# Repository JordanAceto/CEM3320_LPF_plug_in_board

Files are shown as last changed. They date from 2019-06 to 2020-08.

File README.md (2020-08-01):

# NOTE: development of all VCF plug-in boards has been moved here https://github.com/JordanAceto/VCF_plug_in_boards
### This repo will no longer be updated. Follow the above link for the most current files.

# CEM3320 Plug-In Board

Small CEM3320 based low pass filter PCB, designed to plug into a larger motherboard.

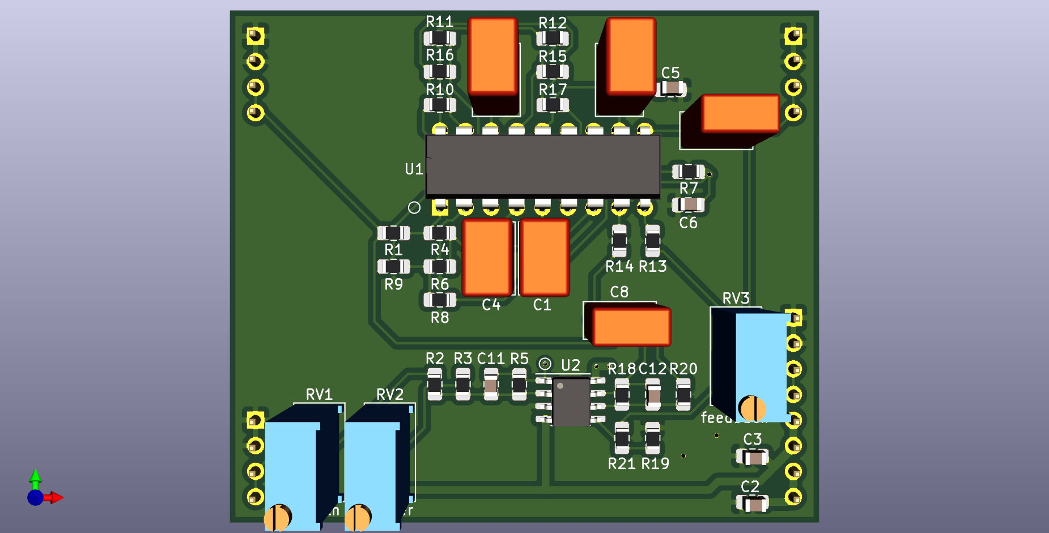
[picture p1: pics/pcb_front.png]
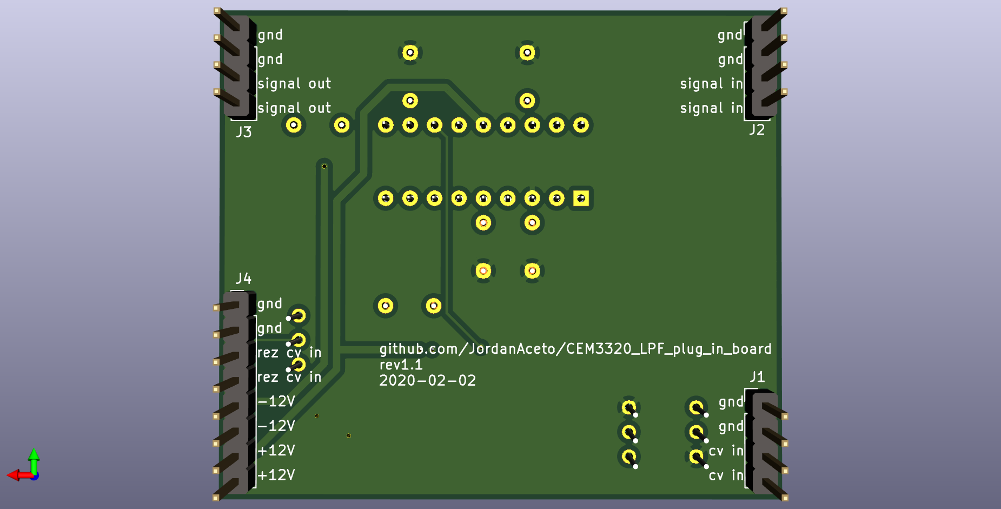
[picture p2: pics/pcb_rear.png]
 

## Details

CEM3320 based LPF with Q compensation. This PCB includes the audio path and CV inputs for frequency and feedback, but does not include any modulation sources.

The intended use for this board is to plug in to a larger motherboard which contains slots for two of these plug-in boards, as well as modulation sources, panel controls, and input/output routing. This motherboard could accept different filter boards sharing this footprint and header layout, for realizing stereo effects of various flavors.

The Q compensation circuit keeps the passband gain from dropping too much when feedback is increased as typically happens with this type of filter. This is a matter of taste. The amount of compensation is set by R20. R20 can be increased to reduce the amount of compensation, resulting in lower passband gain at high feedback settings if a more traditional response is desired.

## Inputs

-Audio in: dry audio input to be filtered.

-Frequency CV in: 0 volts to +2.048 volts, higher voltage = higher sweep.

-Feedback CV in: 0 volts to +2.048 volts, higher voltage = more feedback.

## Outputs

-Audio out: filtered audio output.

## Power Supply Requirements

A bipolar 12 volt power supply is required. This will typically come from the motherboard.

## Calibration

-RV1 (depth trim): trims the depth of incoming frequency CV signals. Turn CW for greater depth and CCW for less depth. Adjust to taste.

-RV2 (center trim): trims the center frequency of the filter. Turn CW for higher center frequency and CCW for lower center frequency. Adjust to taste.

-RV3 (feedback trim): trims the maximum amount of feedback. Turn CW for more maximum feedback and CCW for less maximum feedback. Exercise caution when adjusting this, as extreme settings can result in loud oscillations which could damage your ears or speakers if you are monitoring the sound with a loud amplifier. If you set this trimmer to be right on the edge of oscillation when about +2 volts is applied to the feedback CV input then make sure to sweep the frequency through its entire range, as a setting that doesn't squeal at certain frequency settings may squeal at other settings.

## Parts Ordering
The BOM has a link to a Mouser project with the majority of the parts needed to build the board, with the exception of the CEM3320. There is a link to the synthcube parts page, where the AS3320 is available. This is a functionally equivalent part that is currently in production.

Gerbers can be generated from the kicad_docs.

## License
CC by 4.0

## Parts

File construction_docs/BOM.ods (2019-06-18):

Reference | Quantity | Value | Footprint | Unit Price | Total Price | Product Page
Mouser Parts
C1 C4 C7 C9 | 4 | 220pF | Capacitor_THT:C_Rect_L7.0mm_W4.5mm_P5.00mm | $0.43 | $1.72 | https://www.mouser.com/ProductDetail/WIMA/FKP2D002201D00HSSD?qs=sGAEpiMZZMv1cc3ydrPrFwgzP98AO9idFG3Dn44LbVs%3D
C11 C12 | 2 | 100pF | 0805 | $0.10 | $0.20 | https://www.mouser.com/ProductDetail/KEMET/C0805C101K1HACTU
C5 C6 C2 C3 | 4 | 100nF | 0805 | $0.10 | $0.40 | https://www.mouser.com/ProductDetail/KEMET/C0805C104M5RACTU
C8 C10 | 2 | 470nF | Capacitor_THT:C_Rect_L7.0mm_W3.5mm_P5.00mm | $0.29 | $0.58 | https://www.mouser.com/ProductDetail/WIMA/MKS2C034701C00MSSD
J1 J2 J3 J4 | 1 | breakaway headers | 2.54mm PinHeader | $2.78 | $2.78 | https://www.mouser.com/ProductDetail/TE-Connectivity/4-103185-0
R1 R6 R10 R15 | 4 | 91k | 0805 | $0.12 | $0.48 | https://www.mouser.com/ProductDetail/Bourns/CR0805-FX-9102ELF
R13 | 1 | 18k | 0805 | $0.10 | $0.10 | https://www.mouser.com/ProductDetail/Bourns/CR0805-FX-1802ELF
R14 | 1 | 51k | 0805 | $0.10 | $0.10 | https://www.mouser.com/ProductDetail/Bourns/CR0805-FX-5102ELF
R20 | 1 | 150k | 0805 | $0.10 | $0.10 | https://www.mouser.com/ProductDetail/Bourns/CR0805-FX-1503ELF
R3 | 1 | 330k | 0805 | $0.10 | $0.10 | https://www.mouser.com/ProductDetail/Bourns/CR0805-FX-3303ELF
R4 R9 R12 R17 R2 R18 R21 R19 | 8 | 100k | 0805 | $0.10 | $0.80 | https://www.mouser.com/ProductDetail/Bourns/CR0805-FX-1003ELF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
R5 | 1 | 10k | 0805 | $0.10 | $0.10 | https://www.mouser.com/ProductDetail/Bourns/CR0805-FX-1002ELF
R7 | 1 | 1k2 | 0805 | $0.10 | $0.10 | https://www.mouser.com/ProductDetail/Bourns/CR0805-FX-1201ELF
R8 R11 R16 | 3 | 180k | 0805 | $0.10 | $0.30 | https://www.mouser.com/ProductDetail/Bourns/CR0805-FX-1803ELF
RV1 | 1 | 10k | Bourns_3269W_Vertical | $4.83 | $4.83 | https://www.mouser.com/ProductDetail/Bourns/3269W-1-103LF?qs=sGAEpiMZZMvygUB3GLcD7lKKmqkeksZmGot4dXELruo%3D
RV2 RV3 | 2 | 100k | Bourns_3269W_Vertical | $4.83 | $9.66 | https://www.mouser.com/ProductDetail/Bourns/3269W-1-104LF?qs=sGAEpiMZZMvygUB3GLcD7iPUMwpiXMBsQtXtzdbyTwg%3D
U2 | 1 | TL072 | SOIC-8 | $0.59 | $0.59 | https://www.mouser.com/ProductDetail/Texas-Instruments/TL072CDR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
 |  |  | Mouser total: |  | $22.94
 |  |  | Link To Mouser Project: |  |  | https://www.mouser.com/ProjectManager/ProjectDetail.aspx?AccessID=8d3da38cff
Non-Mouser Parts
U1 | 1 | CEM3320 (AS3320) | DIP-18 | $7.99 | $7.99 | https://synthcube.com/cart/synth-diy/parts/ics-and-semiconductors/alfa-rpar-synth-ics
OSHPark board
 |  |  |  |  |  | https://oshpark.com/shared_projects/EN4ZUsXI

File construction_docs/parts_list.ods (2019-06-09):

Reference | Quantity | Value | Footprint
C1 C4 C7 C9 | 4 | 220pF | Capacitor_THT:C_Rect_L7.0mm_W4.5mm_P5.00mm
C11 C12 | 2 | 100pF | 0805
C5 C6 C2 C3 | 4 | 100nF | 0805
C8 C10 | 2 | 470nF | Capacitor_THT:C_Rect_L7.0mm_W3.5mm_P5.00mm
J1 J2 J3 J4 | 1 | breakaway headers | 2.54mm PinHeader
R1 R6 R10 R15 | 4 | 91k | 0805
R13 | 1 | 18k | 0805
R14 | 1 | 51k | 0805
R20 | 1 | 150k | 0805
R3 | 1 | 330k | 0805
R4 R9 R12 R17 R2 R18 R21 R19 | 8 | 100k | 0805
R5 | 1 | 10k | 0805
R7 | 1 | 1k2 | 0805
R8 R11 R16 | 3 | 180k | 0805
RV1 | 1 | 10k | Bourns_3269W_Vertical
RV2 RV3 | 2 | 100k | Bourns_3269W_Vertical
U2 | 1 | TL072 | SOIC-8
U1 | 1 | CEM3320 (AS3320) | DIP-18

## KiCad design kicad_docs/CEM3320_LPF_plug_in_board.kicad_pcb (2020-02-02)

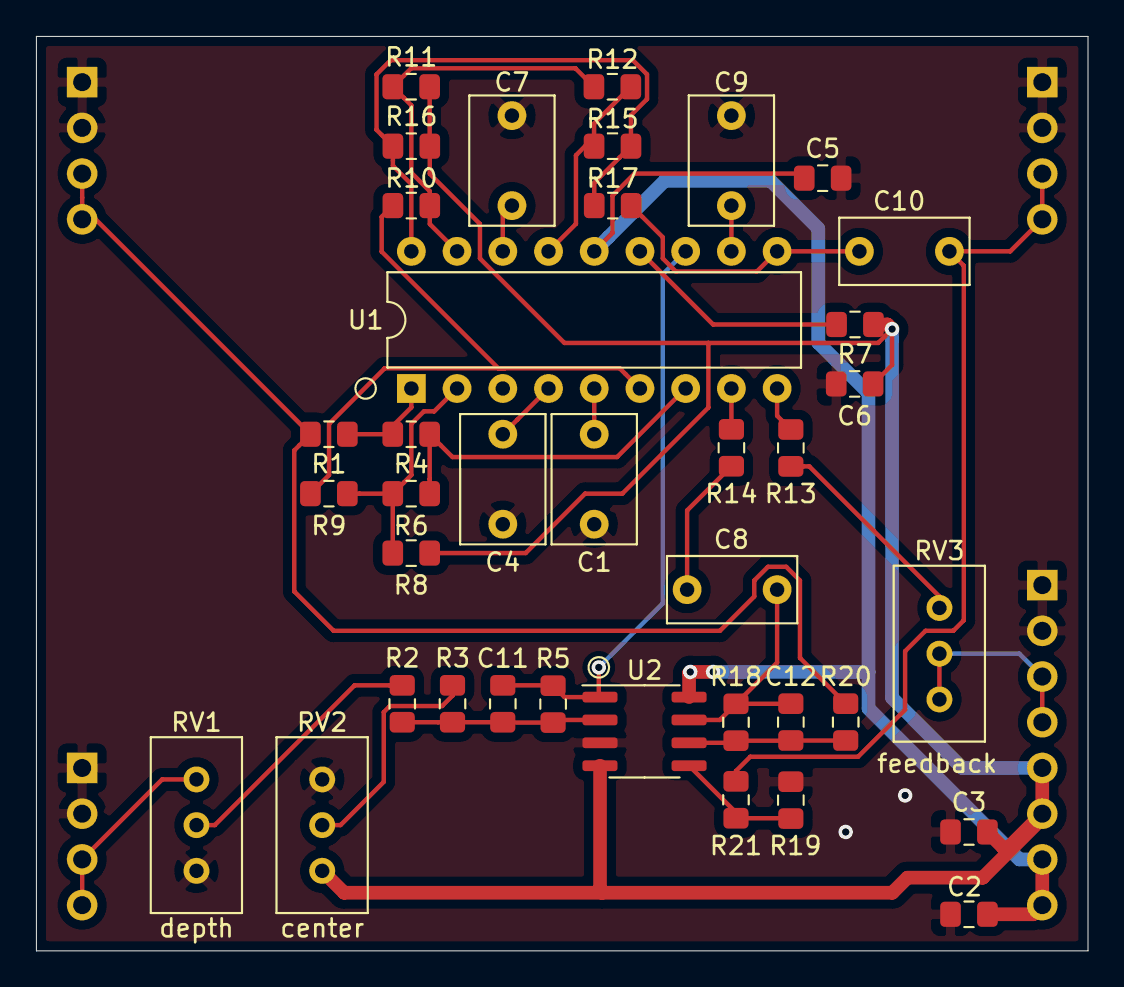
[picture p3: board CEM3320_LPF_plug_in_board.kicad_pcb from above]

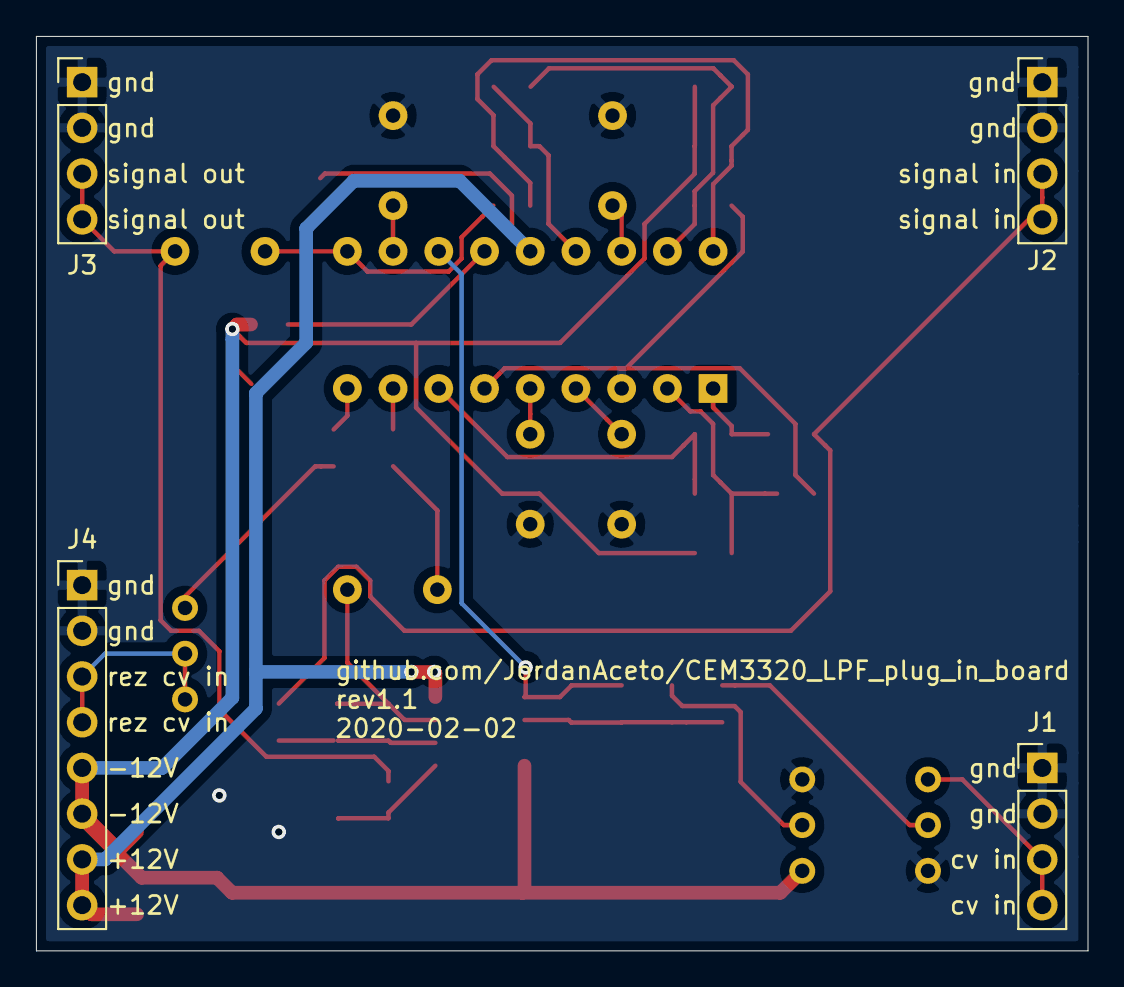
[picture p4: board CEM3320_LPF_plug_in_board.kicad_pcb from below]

Board: 2 copper layers, 58.4 x 50.8 mm, 42 parts (4 on the bottom side), 31 nets.

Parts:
C1, C4, C7, C9: 220pF; C_Rect_L7.0mm_W4.5mm_P5.00mm
C2, C3, C5, C6: 100nF; C_0805_2012Metric_Pad1.15x1.40mm_HandSolder
C8, C10: 470nF; C_Rect_L7.0mm_W3.5mm_P5.00mm
C11, C12: 100pF; C_0805_2012Metric_Pad1.15x1.40mm_HandSolder
J1, J2: signal_in; PinHeader_1x04_P2.54mm_Vertical
J3: signal_out; PinHeader_1x04_P2.54mm_Vertical
J4: Conn_01x08_Male; PinHeader_1x08_P2.54mm_Vertical
R1, R6, R10, R15: 91k; R_0805_2012Metric_Pad1.15x1.40mm_HandSolder
R2, R4, R9, R12, R17, R18, R19, R21: 100k; R_0805_2012Metric_Pad1.15x1.40mm_HandSolder
R3: 330k; R_0805_2012Metric_Pad1.15x1.40mm_HandSolder
R5: 10k; R_0805_2012Metric_Pad1.15x1.40mm_HandSolder
R7: 1k2; R_0805_2012Metric_Pad1.15x1.40mm_HandSolder
R8, R11, R16: 180k; R_0805_2012Metric_Pad1.15x1.40mm_HandSolder
R13: 18k; R_0805_2012Metric_Pad1.15x1.40mm_HandSolder
R14: 51k; R_0805_2012Metric_Pad1.15x1.40mm_HandSolder
R20: 150k; R_0805_2012Metric_Pad1.15x1.40mm_HandSolder
RV1: 10k; Potentiometer_Bourns_3296W_Vertical
RV2, RV3: 100k; Potentiometer_Bourns_3296W_Vertical
U1: CEM3320; DIP-18_W7.62mm
U2: TL072; SOIC-8_3.9x4.9mm_P1.27mm

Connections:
+12V: C2.1, C5.1, J4.7, J4.8, U1.14, U2.8
-12V: C3.2, C6.2, J4.5, J4.6, R7.1, R8.2, R11.2, R16.2, RV2.1, U2.4
/dry: J2.3, J2.4, R1.2, R20.1
/wet: C10.1, J3.3, J3.4, R21.2
GND: C1.2, C2.2, C3.1, C4.2, C5.2, C6.1, C7.2, C9.2, J1.1, J1.2, J2.1, J2.2, J3.1, J3.2, J4.1, J4.2, R19.2, RV1.1, RV2.3, U1.3, U2.3
unnamed: C1.1, U1.5
unnamed: C4.1, U1.4
unnamed: C7.1, U1.16
unnamed: C8.2, R14.1
unnamed: C9.1, U1.11
unnamed: C10.2, R17.1, U1.10
unnamed: C11.1, R2.1, R3.2, R5.2, U2.2
unnamed: C11.2, R5.1, U1.12, U2.1
unnamed: C8.1, C12.1, R18.1, U2.7
unnamed: C12.2, R18.2, R20.2, U2.6
unnamed: J1.3, J1.4, RV1.3
unnamed: J4.3, J4.4, RV3.1, RV3.2
unnamed: R1.1, R4.2, U1.1
unnamed: R2.2, RV1.2
unnamed: R3.1, RV2.2
unnamed: R4.1, R6.2, U1.7
unnamed: R6.1, R8.1, R9.2, U1.2
unnamed: R7.2, U1.13
unnamed: R10.1, R11.1, R12.2, U1.17
unnamed: R9.1, R10.2, U1.6
unnamed: R12.1, R15.2, U1.15
unnamed: R13.1, U1.9
unnamed: R13.2, RV3.3
unnamed: R14.2, U1.8
unnamed: R15.1, R16.1, R17.2, U1.18
unnamed: R19.1, R21.1, U2.5

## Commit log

2019-06-09 add rendered pics of board top and bottom
    [CEM3320_LPF_plug_in_board.kicad_pcb]
2019-06-11 add gerbers
    [CEM3320_LPF_plug_in_board-B_Cu.gbl, CEM3320_LPF_plug_in_board-B_Mask.gbs, CEM3320_LPF_plug_in_board-B_SilkS.gbo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]
2019-06-11 update README to include zipped gerbers
2019-06-18 fix silkscreen issue where R8 and R6 refs overlapped
    [CEM3320_LPF_plug_in_board-B_Cu.gbl, CEM3320_LPF_plug_in_board-B_Mask.gbs, CEM3320_LPF_plug_in_board-B_SilkS.gbo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]
2019-06-18 add link to oshpark
    [BOM.ods]
2019-07-12 fix reversed power pins on TL072 in schm and brd, delete bad gerbers
    [CEM3320_LPF_plug_in_board-B_Cu.gbl, CEM3320_LPF_plug_in_board-B_Mask.gbs, CEM3320_LPF_plug_in_board-B_SilkS.gbo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]
2019-07-12 fix reversed power pins on TL072 in shem pdf
    [CEM3320_LPF_plug_in_board.sch]
2020-02-02 change trimmers to cheaper though hole type
2020-02-02 update pcb silkscreen
    [CEM3320_LPF_plug_in_board.kicad_pcb]
